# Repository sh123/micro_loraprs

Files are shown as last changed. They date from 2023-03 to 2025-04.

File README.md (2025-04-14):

# Arduino Micro LoRA/FSK KISS modem and APRS AX.25 digirepeater

## Introduction
This project is Arduino Micro LoRA/FSK USB KISS modem and standalone APRS AX.25 digirepeater with RA-01 LoRA module. 

Probably, could be easily used with other Arduino boards.

Currently, default radio module is SX1278, such as RA-01/RA-02.

Can be build in two modes:
- As USB KISS LoRA/FSK modem, to be used with Linux AX.25 tools over USB or with APRSDroid or Codec2Talkie applications over USB OTG
- As a standalone LoRA/FSK AX.25 digirepeater optimized for low power consumption

## Configure
Update `include/config.h` with your LoRA modulation settings and module pinouts.

## Build
Use platformio to build required configuration for repeater or modem.

## Photos
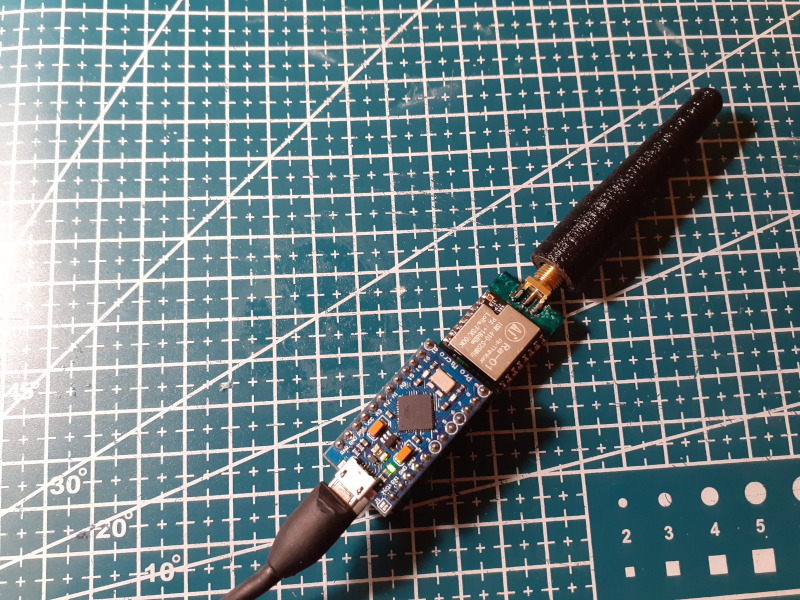
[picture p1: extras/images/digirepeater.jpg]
Device


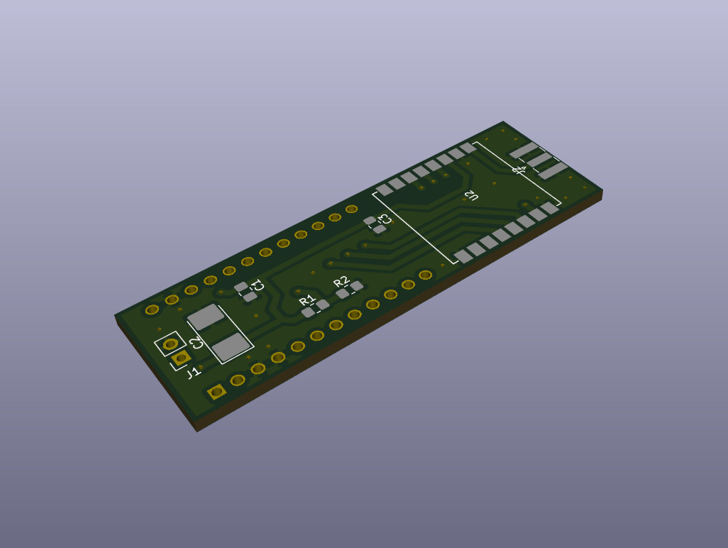
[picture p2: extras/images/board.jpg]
Board


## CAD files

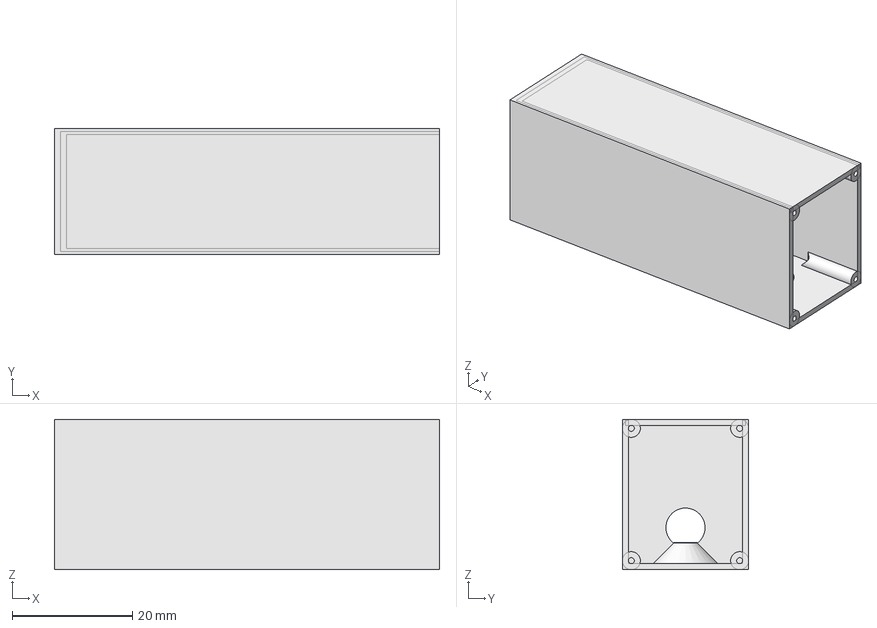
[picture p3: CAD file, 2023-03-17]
extras/cad/base.FCStd
64.0 x 21.0 x 25.0 mm

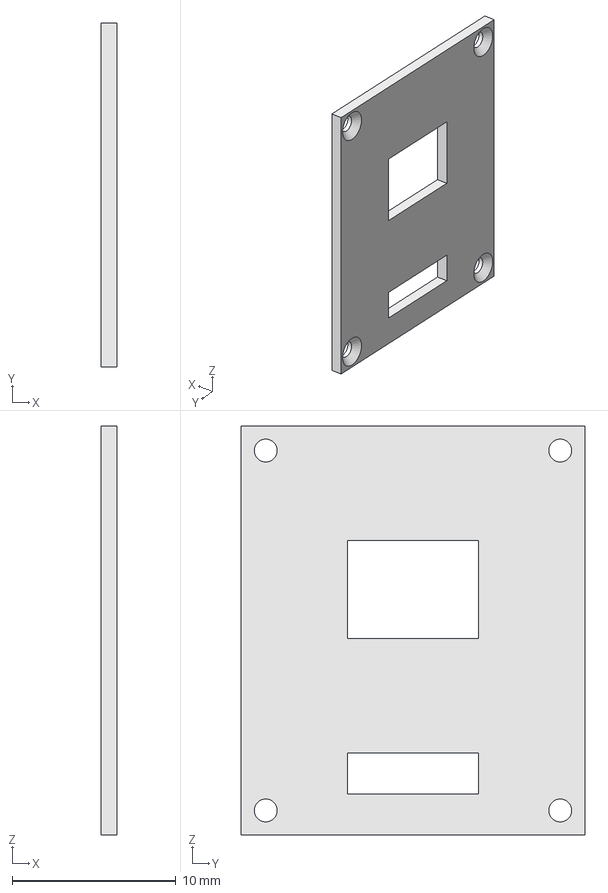
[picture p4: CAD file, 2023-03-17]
extras/cad/cover.FCStd
1.00 x 21.0 x 25.0 mm

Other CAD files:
extras/cad/base.stl
extras/cad/cover.stl

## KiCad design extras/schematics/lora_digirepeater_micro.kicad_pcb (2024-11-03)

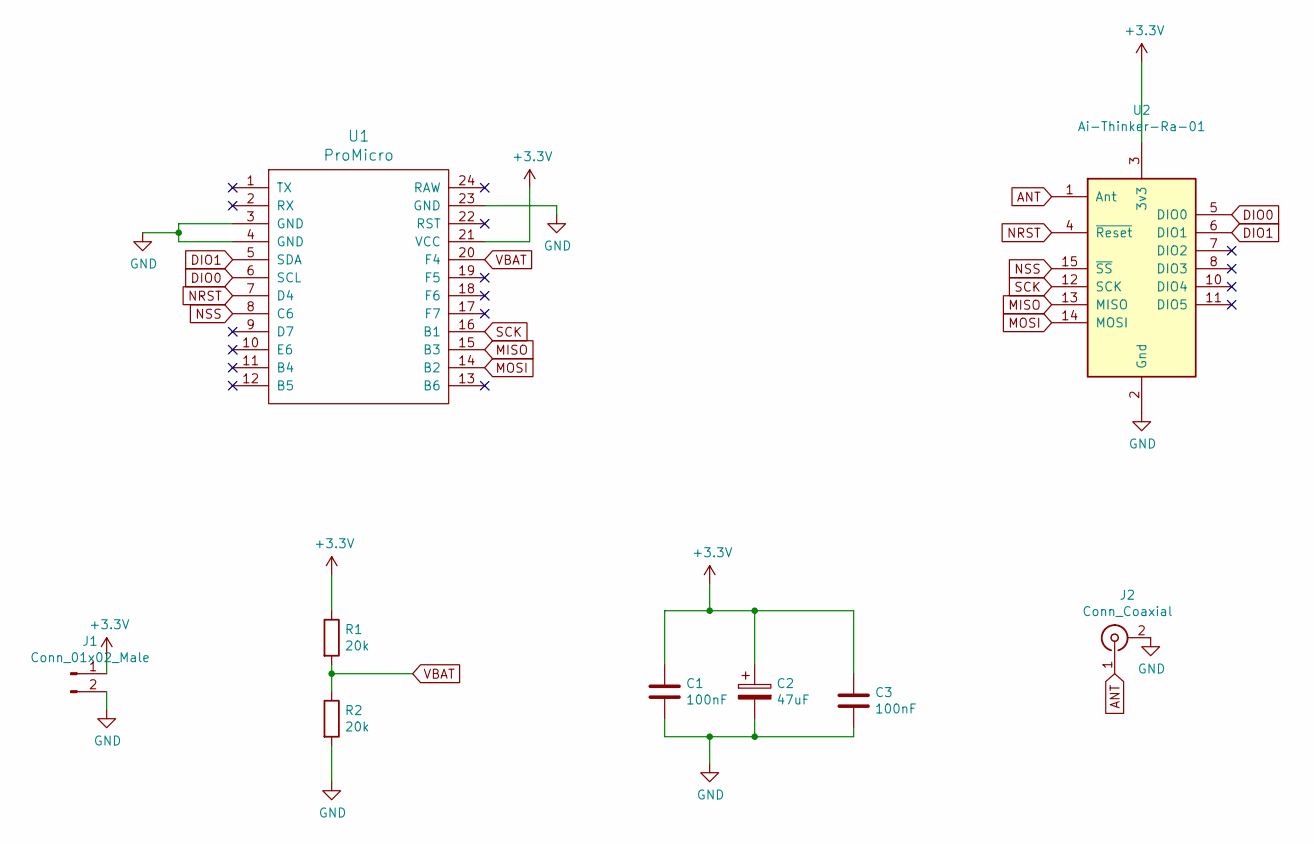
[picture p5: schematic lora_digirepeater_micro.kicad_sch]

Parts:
C1, C3: 100nF; C_0805_2012Metric_Pad1.18x1.45mm_HandSolder
C2: 47uF; CP_EIA-7132-28_AVX-C_Pad2.72x3.50mm_HandSolder
J1: Conn_01x02_Male; PinSocket_1x02_P2.54mm_Vertical
J2: Conn_Coaxial; SMA_Samtec_SMA-J-P-X-ST-EM1_EdgeMount
R1, R2: 20k; R_0805_2012Metric_Pad1.20x1.40mm_HandSolder
U1: ProMicro; ProMicro-NoSilk
U2: Ai-Thinker-Ra-01; Ai-Thinker-Ra-01-LoRa

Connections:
+3V3: C1.1, C2.1, C3.1, J1.1, R1.1, U1.21 (VCC), U2.3 (3v3)
ANT: J2.1 (In), U2.1 (Ant)
DIO0: U1.6 (SCL), U2.5 (DIO0)
DIO1: U1.5 (SDA), U2.6 (DIO1)
GND: C1.2, C2.2, C3.2, J1.2, J2.2 (Ext), R2.2, U1.3 (GND), U1.4 (GND), U1.23 (GND), U2.2 (Gnd), U2.9 (Gnd), U2.16 (Gnd)
MISO: U1.15 (B3), U2.13 (MISO)
MOSI: U1.14 (B2), U2.14 (MOSI)
NRST: U1.7 (D4), U2.4 (~Reset)
NSS: U1.8 (C6), U2.15 (~SS)
SCK: U1.16 (B1), U2.12 (SCK)
VBAT: R1.2, R2.1, U1.20 (F4)

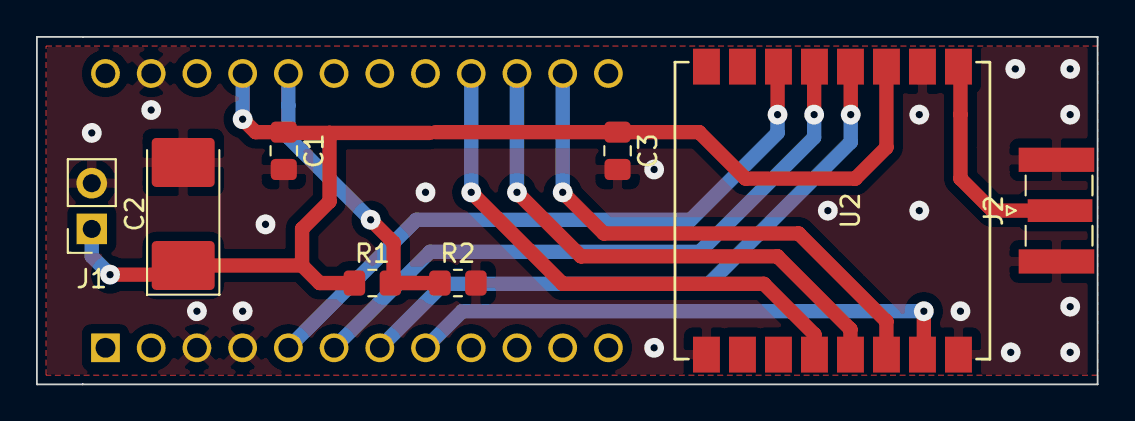
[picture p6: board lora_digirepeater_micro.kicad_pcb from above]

Board: 2 copper layers, 58.9 x 19.3 mm, 9 parts (0 on the bottom side), 11 nets.

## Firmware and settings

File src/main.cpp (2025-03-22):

#include <Arduino.h>
#include <SPI.h>
#include <DebugLog.h>
#include <RadioLib.h>
#include <avr/sleep.h>

#include "ax25_payload.h"
#include "kiss.h"
#include "config.h"
#include "endian.h"

// app config
#define CFG_LOOP_DELAY_MS     20
#define CFG_SERIAL_BAUD_RATE  19200
#define CFG_MAX_PACKET_SIZE   255

// leds
#define CFG_STATUS_LED        17

// kiss parameters
#define DEFAULT_P             255
#define DEFAULT_SLOT_TIME     0

// do not use debugging in modem mode
#ifdef CFG_USE_MODEM
#pragma message("Configured for modem")
#undef CFG_ENABLE_DEBUG
#else
#pragma message("Configured for digirepeater")
#endif

#if CFG_MOD == CFG_MOD_LORA
#pragma message("Configured for LoRa modulation")
#elif CFG_MOD == CFG_MOD_FSK
#pragma message("Configured for FSK modulation")
#else
#error "Unknown modulation type"
#endif

// peripherals
SX1278 radio_ = new Module(CFG_LORA_PIN_NSS, CFG_LORA_PIN_DIO0, CFG_LORA_PIN_RST, CFG_LORA_PIN_DIO1);

// digirepater callsign
AX25::Callsign myCallsign_(CFG_MY_CALLSIGN);

// packet buffers
byte pktBufTx_[CFG_MAX_PACKET_SIZE];
byte pktBufRx_[CFG_MAX_PACKET_SIZE];
int pktBufTxIndex_ = 0;

// receive isr parameters
volatile bool isRxIsrEnabled_ = true;
volatile bool isLoraRxDataAvailable_ = false;

// kiss parameters
Kiss::State kissState_ = Kiss::State::GetStart;
Kiss::DataType kissDataType_ = Kiss::DataType::None;
Kiss::Cmd kissCmd_ = Kiss::Cmd::NoCmd;
long csmaSlotTime_ = DEFAULT_SLOT_TIME;
long csmaSlotTimePrev_ = 0;
byte csmaP_ = DEFAULT_P;

// incoming data isr callback
void isrRxDataAvailable(void) 
{
  if (isRxIsrEnabled_)
    isLoraRxDataAvailable_ = true;
}

// enter deep sleep until packet is received (for low power digirepeating)
void enterDeepSleep() 
{
  LOG_INFO(F("Sleep"));
  sleep_enable();
  set_sleep_mode(SLEEP_MODE_PWR_DOWN);
  digitalWrite(LED_BUILTIN, LOW);
  delay(1000);
  sleep_cpu();
  digitalWrite(LED_BUILTIN, HIGH);
  LOG_INFO(F("Unsleep"));
}

void fatalWithLedStatus(int state) 
{
  LOG_ERROR(F("Radio failed"), state);
  while(true) {
    digitalWrite(CFG_STATUS_LED, HIGH);
    delay(200);
    digitalWrite(CFG_STATUS_LED, LOW);
    delay(200);
  };
}

// configura radio with given parameters
#if CFG_MOD == CFG_MOD_LORA
void setupRadio(long loraFreq, long bw, int sf, int cr, int pwr, int sync, int crcBytes, bool isExplicit) 
{
  // setup lora
  int state = radio_.begin((float)loraFreq / 1e6, (float)bw / 1e3, sf, cr, sync, pwr);
  if (state != RADIOLIB_ERR_NONE) {
    fatalWithLedStatus(state);
  }
  if (isExplicit && sf > 6)
    radio_.explicitHeader();
  else
    radio_.implicitHeader(0xff);
  radio_.setCRC(crcBytes);
  radio_.setPreambleLength(CFG_LORA_PREAMBLE);
  radio_.setDio0Action(isrRxDataAvailable);
  radio_.startReceive();
}
#endif

// configura radio with given parameters
#if CFG_MOD == CFG_MOD_FSK
void setupRadioFsk(long loraFreq, float bitRate, float freqDev, float rxBw, int pwr)
{
  // setup lora
  int state = radio_.beginFSK((float)loraFreq / 1e6, bitRate, freqDev, rxBw, pwr);
  if (state != RADIOLIB_ERR_NONE) {
    fatalWithLedStatus(state);
  }
  radio_.setDio0Action(isrRxDataAvailable);
  radio_.startReceive();
}
#endif

// arduino default setup
void setup() 
{
  // setup serial
#if defined(CFG_ENABLE_DEBUG) || defined(CFG_USE_MODEM)
  Serial.begin(CFG_SERIAL_BAUD_RATE);
  while (!Serial);
#endif

  // status led 
  pinMode(CFG_STATUS_LED, OUTPUT);

  // setup logging
#ifdef CFG_ENABLE_DEBUG
  LOG_SET_LEVEL(DebugLogLevel::LVL_INFO);
  #pragma message("Logging is enabled")
#else
  LOG_SET_LEVEL(DebugLogLevel::LVL_NONE);
  #pragma message("Logging is disabled")
#endif  
  LOG_SET_OPTION(false, false, true);  // disable file, line, enable func

  // setup radio with default parameters
#if CFG_MOD == CFG_MOD_LORA
  setupRadio(CFG_LORA_FREQ, CFG_LORA_BW, CFG_LORA_SF, 
    CFG_LORA_CR, CFG_LORA_PWR, CFG_LORA_SYNC_WORD, 
    CFG_LORA_CRC, CFG_LORA_EXPLICIT);
#elif CFG_MOD == CFG_MOD_FSK
  setupRadioFsk(CFG_LORA_FREQ, CFG_FSK_BIT_RATE, 
    CFG_FSK_FREQ_DEV, CFG_FSK_RX_BW, CFG_LORA_PWR);
#else
#error "Unknown modulation type"
#endif

  LOG_INFO(F("Started"));

  // save power by going sleep in digirepeater mode
#ifndef CFG_USE_MODEM
  enterDeepSleep();
#endif
}

// read packet to the buffer
size_t receiveLoraPacket() 
{
  // get packet size
  size_t packetLength = radio_.getPacketLength();
  if (packetLength == 0) {
    isLoraRxDataAvailable_ = false;
    return 0;
  }
  if (packetLength > CFG_MAX_PACKET_SIZE) {
    //LOG_ERROR(F("Packet size is too large:"), packetLength);
    packetLength = 0;
  } else {
    // read packet
    int state = radio_.readData(pktBufRx_, packetLength);
    if (state != RADIOLIB_ERR_NONE) {
      //LOG_ERROR(F("Read pkt error:"), state);
      packetLength = 0;
    }
  }

  isLoraRxDataAvailable_ = false;
  radio_.startReceive();
  return packetLength;
}

// write packet from the buffer
void sendLoraPacket(size_t packetLength) 
{
  isRxIsrEnabled_ = false;

  // send out 
  int state = radio_.transmit(pktBufTx_, packetLength);
  if (state != RADIOLIB_ERR_NONE) {
    //LOG_ERROR(F("Failed to transmit"), state);
  }
  radio_.finishTransmit();

  isRxIsrEnabled_ = true;
  radio_.startReceive();
}

// read lora packet and transfer to modem
void processLoraPacketAsModem() 
{
  size_t packetLength = receiveLoraPacket();
  if (packetLength == 0) {
    return;
  }

  Serial.write(Kiss::Marker::Fend);
  Serial.write(Kiss::Cmd::Data);

  for (size_t i = 0; i < packetLength; i++) {
    byte rxByte = pktBufRx_[i];

    if (rxByte == Kiss::Marker::Fend) {
      Serial.write(Kiss::Marker::Fesc);
      Serial.write(Kiss::Marker::Tfend);
    }
    else if (rxByte == Kiss::Marker::Fesc) {
      Serial.write(Kiss::Marker::Fesc);
      Serial.write(Kiss::Marker::Tfesc);
    }
    else {
      Serial.write(rxByte);
    }
  }
  Serial.write(Kiss::Marker::Fend);
}

// set hardware from current buffer
void kissSetHardware(int packetSize) 
{
  if (packetSize == CFG_KISS_SET_HARDWARE_SIZE) {
    const struct Kiss::SetHardware * setHardware = reinterpret_cast<const struct Kiss::SetHardware*>(pktBufTx_);
    int pwr = (int16_t)be16toh(setHardware->pwr);
    pwr = pwr < CFG_LORA_PWR_MIN ? CFG_LORA_PWR_MIN
        : pwr > CFG_LORA_PWR_MAX ? CFG_LORA_PWR_MAX : pwr;
    if (setHardware->modType == CFG_MOD_LORA) {
#if CFG_MOD == CFG_MOD_LORA
      setupRadio(
        be32toh(setHardware->freqRx),
        be32toh(setHardware->bw), 
        be16toh(setHardware->sf), 
        be16toh(setHardware->cr), 
        pwr,
        be16toh(setHardware->sync), 
        setHardware->crc ? CFG_LORA_CRC : 0,
        CFG_LORA_EXPLICIT);
#endif
    } else if (setHardware->modType == CFG_MOD_FSK) {
#if CFG_MOD == CFG_MOD_FSK
      setupRadioFsk(
        be32toh(setHardware->freqRx),
        (float)be32toh(setHardware->fskBitRate) / 1e3,
        (float)be32toh(setHardware->fskFreqDev) / 1e3,
        (float)be32toh(setHardware->fskRxBw) / 1e3,
        pwr);
#endif
    }
  }
}

// process one byte from serial, transmit to radio
void kissProcess(byte rxByte) 
{
  // packet overflow
  if (pktBufTxIndex_ > CFG_MAX_PACKET_SIZE) {
    kissState_ = Kiss::State::GetStart;
    pktBufTxIndex_ = 0;
  }
  switch (kissState_) {
    // get kiss start
    case Kiss::State::GetStart:
      if (rxByte == Kiss::Marker::Fend) {
        kissState_ = Kiss::State::GetCmd;
      }
      break;
    // get kiss end
    case Kiss::State::GetEnd:
      if (rxByte == Kiss::Marker::Fend) {
        kissState_ = Kiss::State::GetStart;
      }
      break;
    // get command code
    case Kiss::State::GetCmd:
        switch (rxByte) {
        // data, next packet is the payload
        case Kiss::Cmd::Data:
          pktBufTxIndex_ = 0;
          kissState_ = Kiss::State::GetData;
          kissDataType_ = Kiss::DataType::Raw;
          break;
        // persistence, next byte is a P
        case Kiss::Cmd::P:
          kissState_ = Kiss::State::GetP;
          break;
        // slot time, next byte is a slot time
        case Kiss::Cmd::SlotTime:
          kissState_ = Kiss::State::GetSlotTime;
          break;
        // next byte is the payload of control/set hardware type
        case Kiss::Cmd::SetHardware:
          pktBufTxIndex_ = 0;
          kissState_ = Kiss::State::GetData;
          kissDataType_ = Kiss::DataType::Control;
          break;
        // end byte ignore, no command specified
        case Kiss::Marker::Fend:
          break; 
        default:
          kissState_ = Kiss::State::GetEnd;
          break;
        }
      break;
    // get persistance
    case Kiss::State::GetP:
      csmaP_ = rxByte;
      kissState_ = Kiss::State::GetEnd;
      break;
    // get slot time
    case Kiss::State::GetSlotTime:
      csmaSlotTime_ = (long)rxByte * 10;
      kissState_ = Kiss::State::GetEnd;
      break;
    // get raw data
    case Kiss::State::GetData:
      switch (rxByte) {
        case Kiss::Marker::Fesc:
          kissState_ = Kiss::State::Escape;
          break;
        case Kiss::Marker::Fend:
          // packet is completed send out
          if (kissDataType_ == Kiss::DataType::Raw) {
            sendLoraPacket(pktBufTxIndex_);
            pktBufTxIndex_ = 0;
          // set hardware command is completed, set it
          } else if (kissDataType_ == Kiss::DataType::Control) {
            kissSetHardware(pktBufTxIndex_);
            pktBufTxIndex_ = 0;
          }
          kissState_ = Kiss::State::GetStart;
          break;
        // new byte is read
        default:
          if (kissDataType_ == Kiss::DataType::Raw ||
              kissDataType_ == Kiss::DataType::Control)
            pktBufTx_[pktBufTxIndex_++] = rxByte;
          break;
      }
      break;
    // escape current byte
    case Kiss::State::Escape:
      if (rxByte == Kiss::Marker::Tfend) {
        pktBufTx_[pktBufTxIndex_++] = Kiss::Marker::Fend;
        kissState_ = Kiss::State::GetData;
      }
      else if (rxByte == Kiss::Marker::Tfesc) {
        pktBufTx_[pktBufTxIndex_++] = Kiss::Marker::Fesc;
        kissState_ = Kiss::State::GetData;
      }
      else if (rxByte != Kiss::Marker::Fend) {
        kissState_ = Kiss::State::GetEnd;
      }
      break;
    default:
      kissState_ = Kiss::State::GetStart;
      break;
  } // kissState_
}

// read serial packet and transfer to lora radio
void processSerialPacketAsModem() 
{
  while (Serial.available()) {
    int rxResult = Serial.read();
    // no more data
    if (rxResult == -1) {
      break;
    }
    kissProcess((byte)rxResult);
    yield();
  } 
}

// process incoming packet
void processLoraPacketAsRpt() 
{
  // read packet to the buffer
  size_t packetLength = receiveLoraPacket();
  if (packetLength == 0) return;

  // parse packet
  AX25::Payload payload(pktBufRx_, packetLength);
  if (!payload.IsValid()) {
    LOG_WARN(F("Not AX25"));
    return;
  }
  payload.Dump();

  // digireat
  if (!payload.Digirepeat(myCallsign_)) {
    LOG_INFO(F("RPT skip"));
    return;
  }

  // serialize to ax25 packet
  int txPacketLength = payload.ToBinary(pktBufRx_, CFG_MAX_PACKET_SIZE);
  if (txPacketLength <= 0) {
    LOG_WARN(F("AX25 to bin fail"));
    return;
  }

  // send lora packet
  sendLoraPacket(txPacketLength);
}

// arduino loop
void loop() 
{
#ifdef CFG_USE_MODEM
  if (isLoraRxDataAvailable_) {
    processLoraPacketAsModem();
  } else {
    long currentTime = millis();
    if (currentTime > csmaSlotTimePrev_ + csmaSlotTime_ && random(0, 255) < csmaP_) {
      if (Serial.available()) {
        processSerialPacketAsModem();
      }
      csmaSlotTimePrev_ = currentTime;
    }
  }
#else
  if (isLoraRxDataAvailable_) {
    processLoraPacketAsRpt();
    enterDeepSleep();
  }
#endif
  delay(CFG_LOOP_DELAY_MS);
}

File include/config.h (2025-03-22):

#ifndef CONFIG_H
#define CONFIG_H

// radio module parameters
#define CFG_LORA_FREQ         433.775E6
#define CFG_LORA_PWR          10
#define CFG_LORA_PWR_MIN      2
#define CFG_LORA_PWR_MAX      20

// modulation selection
#define CFG_MOD_LORA          0
#define CFG_MOD_FSK           1
#ifdef CFG_USE_FSK
#define CFG_MOD               CFG_MOD_FSK
#else
#define CFG_MOD               CFG_MOD_LORA
#endif

// lora parameters
#define CFG_LORA_SYNC_WORD    0x12
#define CFG_LORA_BW           125.00e3
#define CFG_LORA_SF           7
#define CFG_LORA_CR           6
#define CFG_LORA_CRC          1
#define CFG_LORA_EXPLICIT     true
#define CFG_LORA_PREAMBLE     8

// fsk parameters
#define CFG_FSK_BIT_RATE      4.8
#define CFG_FSK_FREQ_DEV      1.2
#define CFG_FSK_RX_BW         9.7

// lora pinouts
#define CFG_LORA_PIN_NSS      5
#define CFG_LORA_PIN_RST      4
#define CFG_LORA_PIN_DIO0     3
#define CFG_LORA_PIN_DIO1     2

// generic parameters
#define CFG_MY_CALLSIGN       "N0CALL-11"

#endif // CONFIG_H

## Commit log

2023-03-17 Added cad files
    [base.FCStd, base.stl, cover.FCStd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]
2024-11-03 Added missing files
    [lora_digirepeater_micro.kicad_pcb, lora_digirepeater_micro.kicad_sch]
2025-03-22 Restrict power ranges and add failure led blinking loop to diagnose modem init failure
    [config.h, main.cpp]
